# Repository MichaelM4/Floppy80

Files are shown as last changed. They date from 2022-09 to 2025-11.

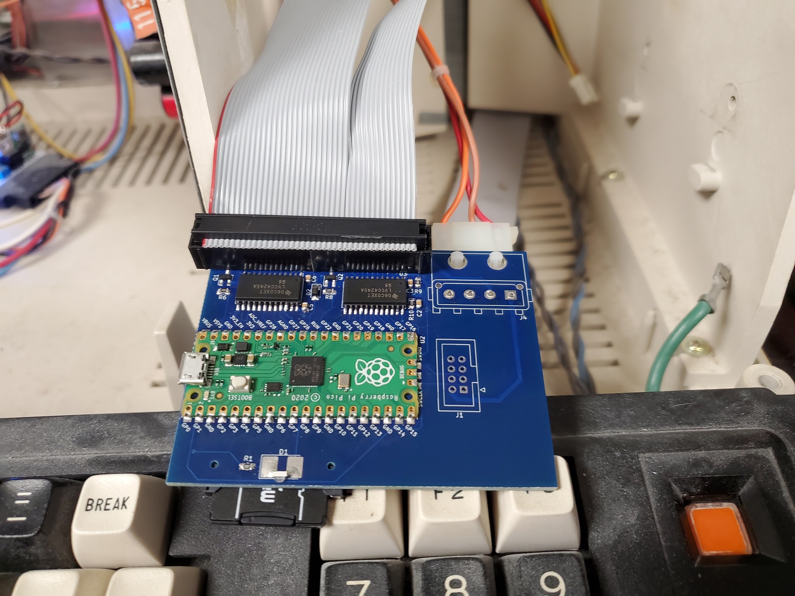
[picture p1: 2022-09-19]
20220129_120431.jpg

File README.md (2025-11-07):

########################################################################

Floppy 80 for the TRS-80 Model 3/4 NGA

The Floppy80 emulates up to four floppy drives.

Configuration of the Floppy80 is performed with the placement of
files on the SD-Card inserted in its card reader.
The files are as follows:

boot.cfg
- specified the defaul ini file to load at reset of the Floppy80
  when the floppy 80 boots or is reset it reads the contents of
  the boot.cfg to determine the default configuration ini file.

ini files
- specifies the disk images to load after reset.

  ini options
  - Drive0 - specified the image to load for drive :0
  - Drive1 - specified the image to load for drive :1
  - Drive2 - specified the image to load for drive :2
  - Drive3 - specified the image to load for drive :3

dmk files
- these are virtual disk images with a specific file format
  that allows them to be generated and used with a number
  of existing programs and simulators.

hfe files
- these are virtual disk images with a specific file format
  that allows them to be generated and used with a number
  of existing programs and simulators.

########################################################################

FDC utility
- Is a utility to interact with the Floppy80 from within the
  TRS-80 Model 3/4 operating environment.  Versions of FDC exist
  for the following operating systems

  - CPM
  - LDOS
  - TRSDOS

  FDC.COM is used with the CP/M OS and
  FDC/CMD is used with the rest.

  Usage

  FDC OPT PARM1:drive

  Where:
  - OPT is one of the following
    - STA - returns the status of the Floppy80.
    - INI - switches between tyhe differnt ini file on the SD-Card.
    - DMK - allows the mounting of DMK disk images in the root folder
            of the SD-Card for a specified drive (0, 1, 2 or 3).
    - IMP - imports a file from the root folder of the SD-Card
            into one of the mounted disk images (0, 1, 2 or 3).

  FDC STA
  - Displays the contects to the ini file specified by boot.cfg

  FDC INI filename.exe
  - filename.exe is optional.  If not specified and list of ini files
    on the SD-Card will be displayed allow you to select the one to
    write to boot.cfg.  When specified FDC will bypass the file
    selection process.

  FDC DMK filename.exe n
  - filename.exe:n is optional.  When specified it will mount
    the dmk file names by filename.exe into the drive specified
    by n.  For example

    FDC DMK LDOS-DATA.DMK 2

    will mount the dmk file LDOS-DATA.DMK into drive :2

    If filename.exe:n is not specfied a list of dmk files
    will be listed allowing you to select on and the drive
    to mount it into.

  FDC IMP filename.exe:n
  - imports the specified file from the root folder of the
    FAT32 formated SD-Card to the disk image indicated by n.

########################################################################

Building Source
- Floppy80 firmware
  - Uses VSCode and the Pi Pico extension.

- FDC TRS (utility for the TRSDOS related utility)
  
  - zmac fdc.asm

- FDC CP/M (utility for the CP/M related utility)
  1. Import the source file onto a working CP/M diskette.
  
       D:\TRS-80\TRSUtils\trswrite cpm-work2.dmk -o fdc.c
     
  2. Run TRS80GP loading the CP/M disk images.
     
       start trs80gp -m4 -vs -frehd -frehd_dir source -turbo -mem 128 -d0 M4-CPM-MONTEZUMA-v22.dmk -d1 cpm-hc-disk.dmk -d2 cpm-work1.dmk -d3 cpm-work2.dmk
     
  3. Compile the C source using the Hi-Tech C compilier.

     b:
     c d:fdc.c

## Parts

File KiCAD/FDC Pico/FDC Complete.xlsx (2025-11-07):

Qty | Description | Cost | Part Number | Supplier
 | PCB Components | $14.05
 | PCB FDC | $2.00
 | PCB Card Edge | $1.00
1 | 2 x 20 male header | $0.50 | ED10529-ND | Digikey
1 | 2x20 female to female ribbon cable (30 cm) | $2.50 ea |  | Amazon
 |  | $17.55

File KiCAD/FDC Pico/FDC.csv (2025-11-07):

Source: | D:\TRS-80\Projects\fdc\KiCAD\FDC Pico\FDC.kicad_sch
Date: | 3/24/2022 11:33
Tool: | Eeschema (6.0.1)
Generator: | C:\Program Files\KiCad\6.0\bin\scripting\plugins/bom_csv_grouped_by_value.py
Component Count: | 20
Individual Components:
Item | Qty | Reference(s) | Value | Cost | Digikey | Manufacturer | Mouser | Vendor
 |  | C2 | 100nF | 0.1 | 732-8080-1-ND
 |  | C3 | 100nF | 0.1 | 732-8080-1-ND
 |  | C5 | 100nF | 0.1 | 732-8080-1-ND
 |  | C6 | 100nF | 0.1 | 732-8080-1-ND
 |  | D1 | LED | 0.72 | 754-1519-1-ND
 |  | D2 | 1N4148WTR | 0.14 | 1655-1360-1-ND
 |  | J1 | Conn_02x04_Odd_Even |  |  |  |  | 900-0702460801-ND
 |  | J3 | SD_Card | 4.3 | 478-4058-1-ND | 145638109511859+ | 581-145638109511859+
 |  | J4 | Conn_01x04_Female | 2.22 | A25430-ND | 641737-1
 |  | J5 | Conn_02x20_Odd_Even | 0.5 | ED10529-ND
 |  | Q1 | SBC817-40LT1G | 0.28 | SBC817-40LT1GOSCT-ND
 |  | Q2 | SBC817-40LT1G | 0.28 | SBC817-40LT1GOSCT-ND
 |  | R1 | 100 | 0.1 | RMCF0805FT100RCT-ND
 |  | R6 | 1k | 0.1 | A106056CT-ND
 |  | R8 | 1k | 0.1 | A106056CT-ND
 |  | R9 | 4.7k | 0.1 | A129757CT-ND
 |  | R10 | 4.7k | 0.1 | A129757CT-ND
 |  | U2 | Pico | 4 | 2648-SC0915CT-ND
 |  | U3 | SN74LVCC4245ADWR | 1.82 | 296-26634-1-ND
 |  | U5 | SN74LVCC4245ADWR | 1.82 | 296-26634-1-ND
Collated Components:
Item | Qty | Reference(s) | Value | Cost | Digikey | Manufacturer | Mouser | Vendor
1 | 4 | C2, C3, C5, C6 | 100nF | 0.1 | 732-8080-1-ND
2 | 1 | D1 | LED | 0.72 | 754-1519-1-ND
3 | 1 | D2 | 1N4148WTR | 0.14 | 1655-1360-1-ND
4 | 1 | J1 | Conn_02x04_Odd_Even |  |  |  |  | 900-0702460801-ND
5 | 1 | J3 | SD_Card | 4.3 | 478-4058-1-ND | 145638109511859+ | 581-145638109511859+
6 | 1 | J4 | Conn_01x04_Female | 2.22 | A25430-ND | 641737-1
7 | 1 | J5 | Conn_02x20_Odd_Even | 0.5 | ED10529-ND
8 | 2 | Q1, Q2 | SBC817-40LT1G | 0.28 | SBC817-40LT1GOSCT-ND
9 | 1 | R1 | 100 | 0.1 | RMCF0805FT100RCT-ND
10 | 2 | R6, R8 | 1k | 0.1 | A106056CT-ND
11 | 2 | R9, R10 | 4.7k | 0.1 | A129757CT-ND
12 | 1 | U2 | Pico | 4 | 2648-SC0915CT-ND
13 | 2 | U3, U5 | SN74LVCC4245ADWR | 1.82 | 296-26634-1-ND

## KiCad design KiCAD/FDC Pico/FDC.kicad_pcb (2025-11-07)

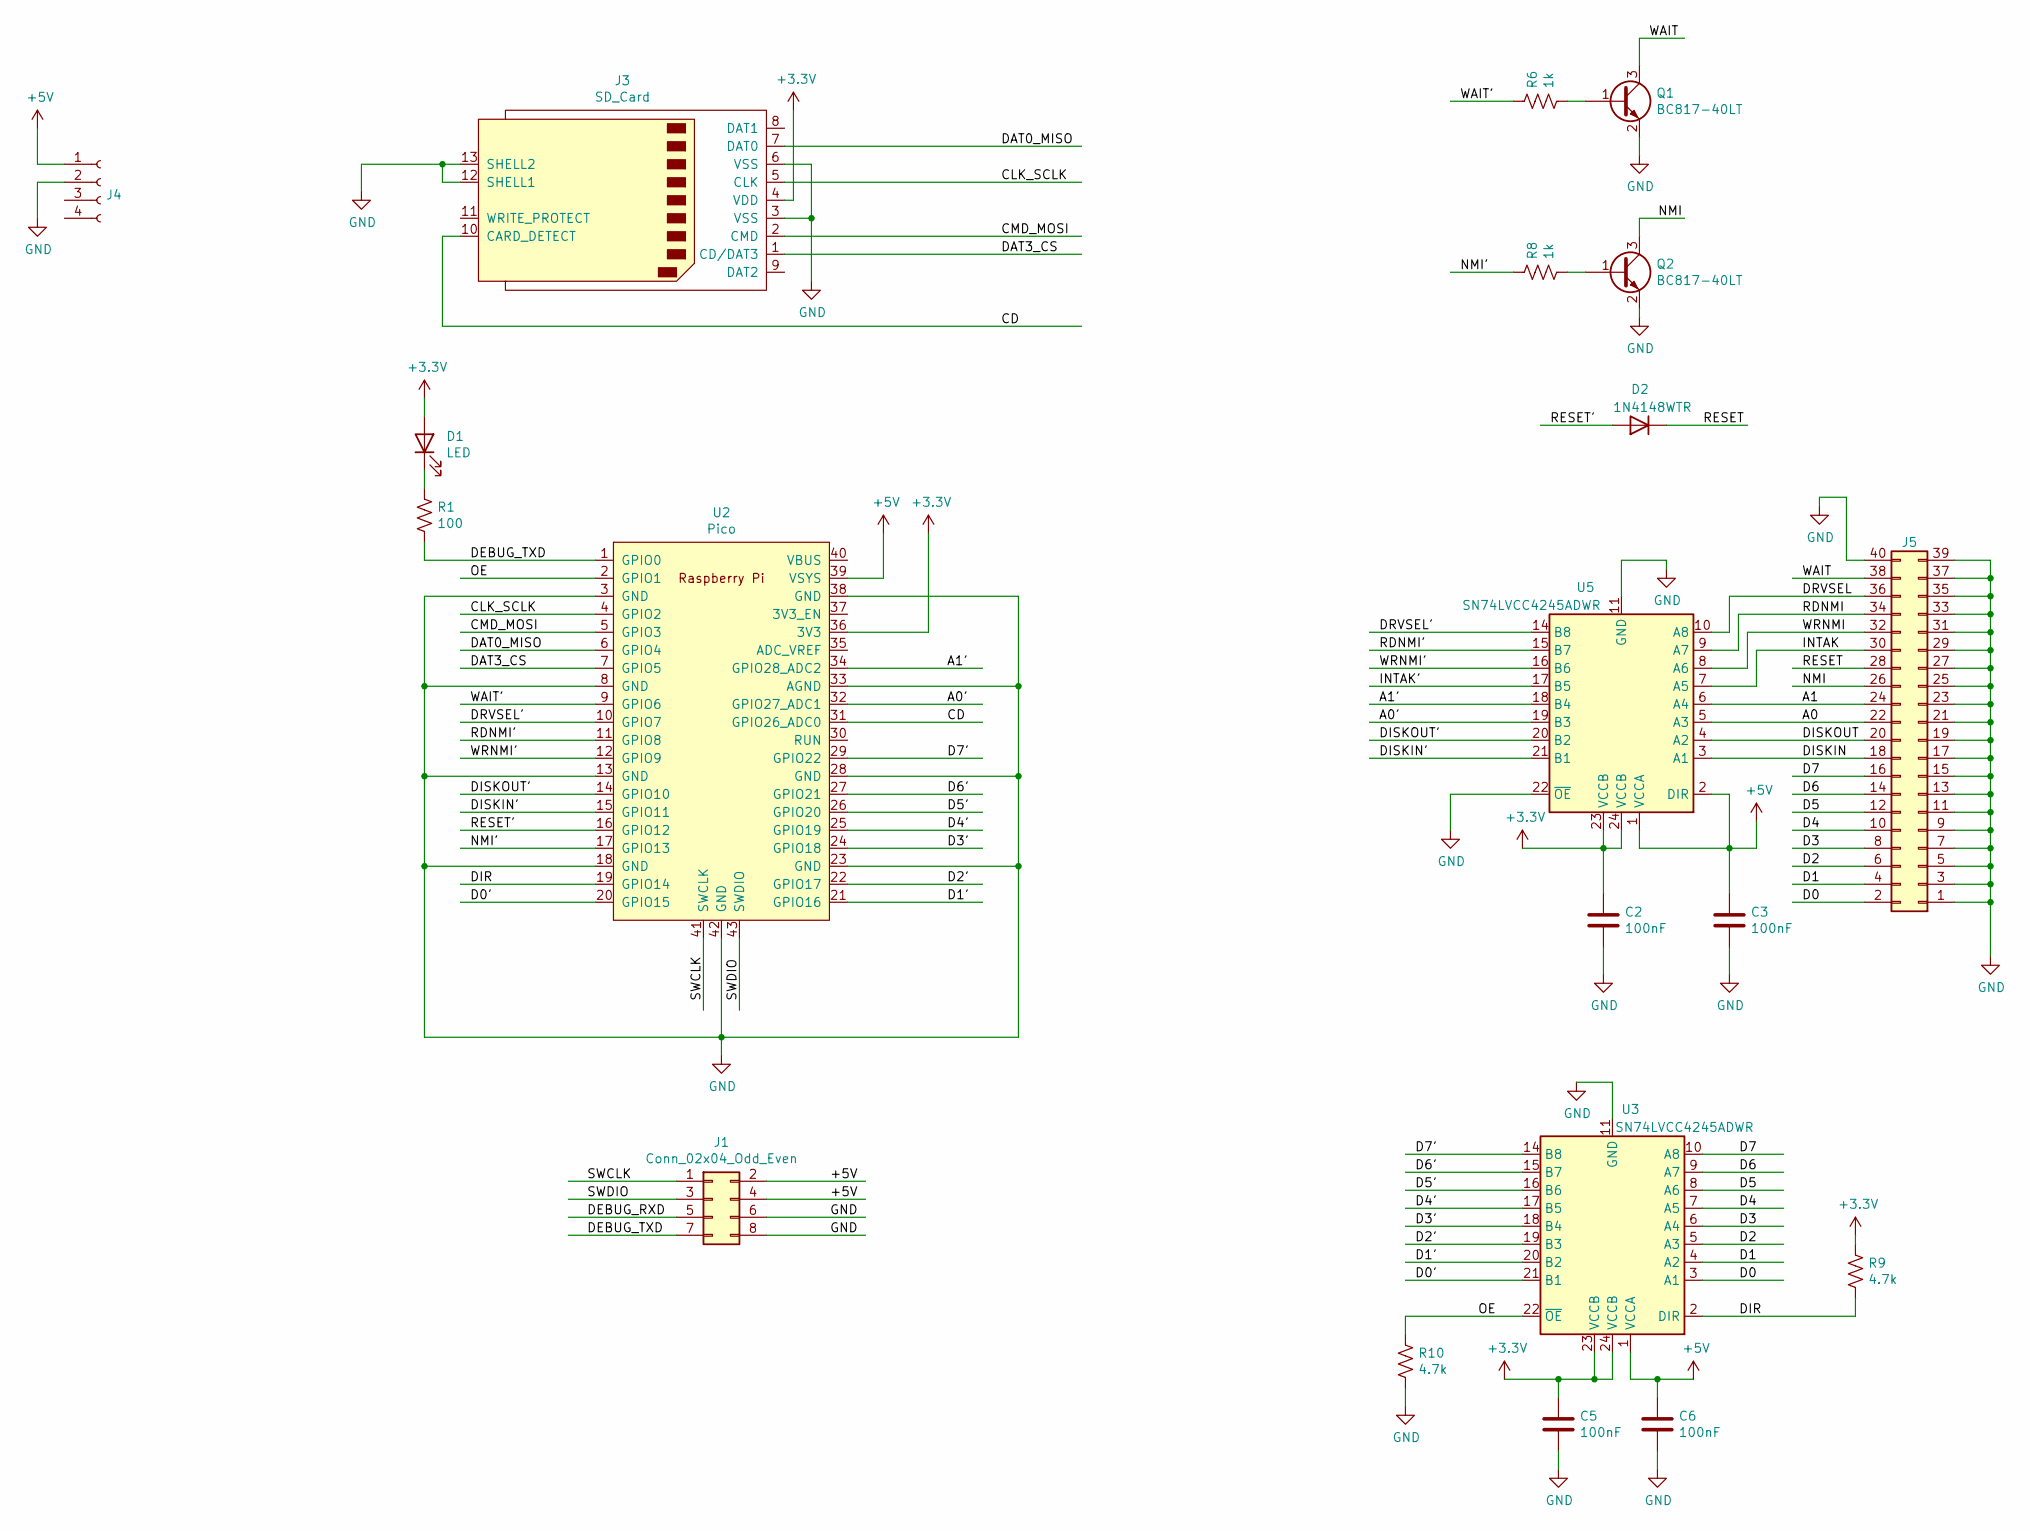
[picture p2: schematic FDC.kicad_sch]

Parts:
C2, C3, C5, C6: 100nF; C_0603_1608Metric_Pad1.08x0.95mm_HandSolder; Digikey 732-8080-1-ND
D1: LED; LED_2816_7142Metric_Pad3.20x4.45mm_HandSolder; Digikey 754-1519-1-ND
D2: 1N4148WTR; D_1206_3216Metric_Pad1.42x1.75mm_HandSolder; Digikey 1655-1360-1-ND
J1: Conn_02x04_Odd_Even; IDC-Header_2x04_P2.54mm_Vertical
J3: SD_Card; SD_Kyocera_145638109511859+; Digikey 478-4058-1-ND
J4: Conn_01x04_Female; TE_MATE-N-LOK_350211-1_1x04_P5.08mm_Horizontal; Digikey A25430-ND
J5: Conn_02x20_Odd_Even; PinHeader_2x20_P2.54mm_Vertical; Digikey ED10529-ND
Q1: BC817-40LT; SOT-23_Handsoldering; Digikey BC817-40LT3GOSCT-ND
Q2: BC817-40LT; SOT-23_Handsoldering; Digikey BC817-40FDICT-ND
R1: 100; R_0805_2012Metric_Pad1.20x1.40mm_HandSolder; Digikey RMCF0805FT100RCT-ND
R6, R8: 1k; R_0805_2012Metric_Pad1.20x1.40mm_HandSolder; Digikey A106056CT-ND
R9, R10: 4.7k; R_0805_2012Metric_Pad1.20x1.40mm_HandSolder; Digikey A129757CT-ND
U2: Pico; RPi_Pico_SMD_TH; Digikey 2648-SC0915CT-ND
U3, U5: SN74LVCC4245ADWR; SOIC-24W_7.5x15.4mm_P1.27mm; Digikey 296-26634-1-ND

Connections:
+3V3: C2.1, C5.1, D1.2 (A), J3.4 (VDD), R9.1, U2.36 (3V3), U3.23 (VCCB), U3.24 (VCCB), U5.23 (VCCB), U5.24 (VCCB)
+5V: C3.1, C6.1, J1.2, J1.4, J4.1, U2.39 (VSYS), U3.1 (VCCA), U5.1 (VCCA), U5.2 (DIR)
/A0: J5.22, U5.5 (A3)
/A0': U2.32 (GPIO27_ADC1), U5.19 (B3)
/A1: J5.24, U5.6 (A4)
/A1': U2.34 (GPIO28_ADC2), U5.18 (B4)
/CD: J3.10 (CARD_DETECT), U2.31 (GPIO26_ADC0)
/CLK_SCLK: J3.5 (CLK), U2.4 (GPIO2)
/CMD_MOSI: J3.2 (CMD), U2.5 (GPIO3)
/D0: J5.2, U3.3 (A1)
/D0': U2.20 (GPIO15), U3.21 (B1)
/D1: J5.4, U3.4 (A2)
/D1': U2.21 (GPIO16), U3.20 (B2)
/D2: J5.6, U3.5 (A3)
/D2': U2.22 (GPIO17), U3.19 (B3)
/D3: J5.8, U3.6 (A4)
/D3': U2.24 (GPIO18), U3.18 (B4)
/D4: J5.10, U3.7 (A5)
/D4': U2.25 (GPIO19), U3.17 (B5)
/D5: J5.12, U3.8 (A6)
/D5': U2.26 (GPIO20), U3.16 (B6)
/D6: J5.14, U3.9 (A7)
/D6': U2.27 (GPIO21), U3.15 (B7)
/D7: J5.16, U3.10 (A8)
/D7': U2.29 (GPIO22), U3.14 (B8)
/DAT0_MISO: J3.7 (DAT0), U2.6 (GPIO4)
/DAT3_CS: J3.1 (CD/DAT3), U2.7 (GPIO5)
/DEBUG_TXD: J1.7, R1.2, U2.1 (GPIO0)
/DIR: R9.2, U2.19 (GPIO14), U3.2 (DIR)
/DISKIN: J5.18, U5.3 (A1)
/DISKIN': U2.15 (GPIO11), U5.21 (B1)
/DISKOUT: J5.20, U5.4 (A2)
/DISKOUT': U2.14 (GPIO10), U5.20 (B2)
/DRVSEL: J5.36, U5.10 (A8)
/DRVSEL': U2.10 (GPIO7), U5.14 (B8)
/INTAK: J5.30, U5.7 (A5)
/NMI: J5.26, Q2.3 (C)
/NMI': R8.1, U2.17 (GPIO13)
/OE: R10.1, U2.2 (GPIO1), U3.22 (~OE)
/RDNMI: J5.34, U5.9 (A7)
/RDNMI': U2.11 (GPIO8), U5.15 (B7)
/RESET: D2.1 (K), J5.28
/RESET': D2.2 (A), U2.16 (GPIO12)
/SWCLK: J1.1, U2.41 (SWCLK)
/SWDIO: J1.3, U2.43 (SWDIO)
/WAIT: J5.38, Q1.3 (C)
/WAIT': R6.1, U2.9 (GPIO6)
/WRNMI: J5.32, U5.8 (A6)
/WRNMI': U2.12 (GPIO9), U5.16 (B6)
GND: C2.2, C3.2, C5.2, C6.2, J1.6, J1.8, J3.3 (VSS), J3.6 (VSS), J3.12 (SHELL1), J3.13 (SHELL2), J4.2, J5.1, J5.3, J5.5, J5.7, J5.9, J5.11, J5.13, J5.15, J5.17, J5.19, J5.21, J5.23, J5.25, J5.27, J5.29, J5.31, J5.33, J5.35, J5.37, J5.39, J5.40, Q1.2 (E), Q2.2 (E), R10.2, U2.3 (GND), U2.8 (GND), U2.13 (GND), U2.18 (GND), U2.23 (GND), U2.28 (GND), U2.33 (AGND), U2.38 (GND), U2.42 (GND), U3.11 (GND), U3.12 (GND), U3.13 (GND), U5.11 (GND), U5.12 (GND), U5.13 (GND), U5.22 (~OE)
unnamed: D1.1 (K), R1.1
unnamed: Q1.1 (B), R6.2
unnamed: Q2.1 (B), R8.2

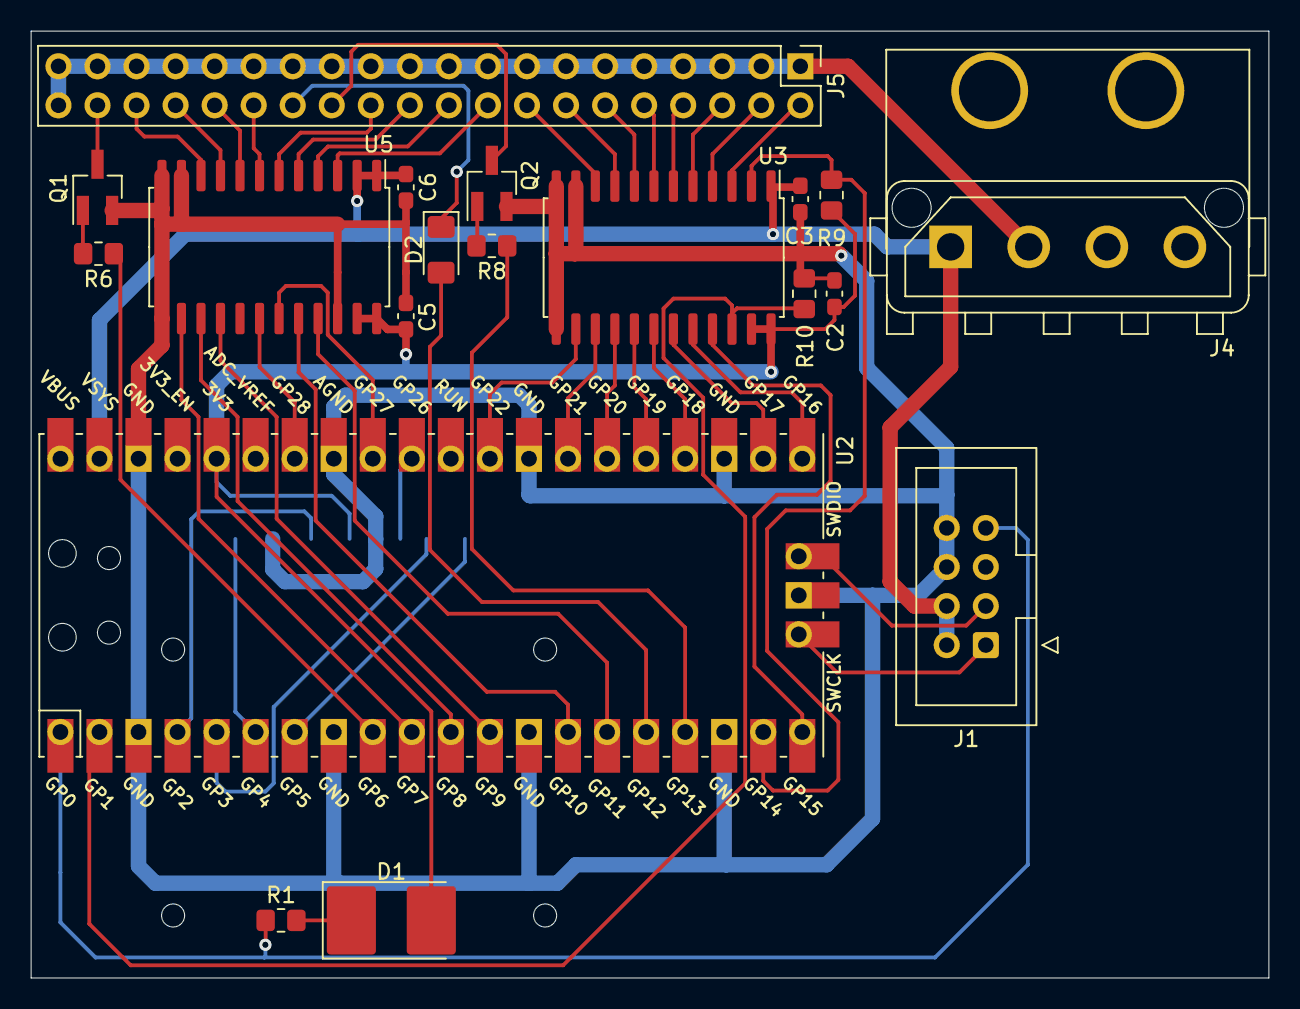
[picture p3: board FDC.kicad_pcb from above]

Board: 2 copper layers, 80.5 x 61.6 mm, 20 parts (1 on the bottom side), 53 nets.

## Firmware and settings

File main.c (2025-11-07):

#include <stdio.h>
#include <string.h>
#include "pico/stdlib.h"

#include "hardware/pio.h"
#include "hardware/irq.h"
#include "hardware/regs/intctrl.h"
#include "hardware/clocks.h"
#include "hardware/structs/systick.h"

#include "fdc.pio.h"
#include "Defines.h"
#include "sd_core.h"
#include "fdc.h"
#include "system.h"

#if (ENABLE_TRACE_LOG == 1)
	void RecordBusHistory(DWORD dwBus, BYTE byData);
#endif

///////////////////////////////////////////////////////////////////////////////
// API documentions is located at
// https://raspberrypi.github.io/pico-sdk-doxygen/
///////////////////////////////////////////////////////////////////////////////

///////////////////////////////////////////////////////////////////////////////
// to get memory usage of the compilied program enter
//
//     size build/fdc.elf
//
// in a bash terminal window
//
// Output is
// - text indicates code size (Read Only)
// - data is initialized data (R/W)
// - bss is uninitialize data (R/W)
///////////////////////////////////////////////////////////////////////////////

#define ENABLE_LED 1
#define HOST_SEQUENCE_COUNT 9

BYTE g_byHostSequence[HOST_SEQUENCE_COUNT] = {0x80, 0x7F, 0x81, 0xFE, 0x82, 0xFD, 0x83, 0xFC, 0x84};

//-----------------------------------------------------------------------------

pio_sm_config g_pio_config;
PIO           g_pio;
uint          g_sm, g_offset;

DWORD         g_dwPreviousTimeCount;
DWORD         g_dwRotationTime;
DWORD         g_dwIndexTime;
DWORD         g_dwResetTime;
BYTE          g_byMonitorReset;

BYTE          g_byMotorWasOn;
BYTE          g_byFlushTraceBuffer;

uint32_t      g_nTimeNow;
uint32_t      g_nPrevTime;

//-----------------------------------------------------------------------------
void DetectHostSequnce(BYTE byData)
{
	if ((g_FDC.nWrHostSequence < HOST_SEQUENCE_COUNT) && (g_byHostSequence[g_FDC.nWrHostSequence] == byData))
	{
		++g_FDC.nWrHostSequence;
	}
	else
	{
		g_FDC.nWrHostSequence = 0;
		g_FDC.nRdHostSequence = 0;
	}
}

///////////////////////////////////////////////////////////////////////////////
// restart pio code to release WAIT state
void ReleaseWait(void)
{
	// push pin direction mask into tx fifo (this way the pio state machine does not need to generate it)
	pio_sm_put(g_pio, g_sm, ~GPIO_IN_MASK >> WAIT_PIN);

	// restart the pio state machine at its first instruction (the address for which is g_offset)
	// set x, g_offset
	//   [3 bit opcode]      = 111
	//   [5 bits = delay]    = 00000
	//   [3 bits detination] = 001 = x
	//   [5 bits data]       = g_offset
	//   -------------------------------
	//   1110  0000 0010 0000 + [offset]
	pio_sm_exec(g_pio, g_sm, 0xE020 + g_offset);

	// mov pc, x
	//   [3 bit opcode]      = 101
	//   [5 bits = delay]    = 00000
	//   [3 bits detination] = 101 = pc
	//   [2 bits Op]         = 00  = None
	//   [3 bits Source]     = 001 = x
	//   -------------------------------
	//   1010  0000 1010 0001
	pio_sm_exec(g_pio, g_sm, 0xA0A1);
}

//----------------------------------------------------------------------------
void GetCommandText(char* psz, BYTE byCmd)
{
	char szBuf[128];
	
	*psz = 0;

	if ((byCmd & 0xF0) == 0) // 0000xxxx
	{
		strcpy(psz, "CMD: Restore");
	}
	else if ((byCmd & 0xF0) == 0x10) // 0001xxxx
	{
		sprintf(psz, "CMD: SEEK 0x%02X, From 0x%02X", g_FDC.byData, g_FDC.byTrack);
	}
	else if ((byCmd & 0xF0) == 0x20) // 0010xxxx
	{
		strcpy(psz, "CMD: Step, Do Not Update Track Register");
	}
	else if ((byCmd & 0xF0) == 0x30) // 0011xxxx
	{
		strcpy(psz, "CMD: Step, Update Track Register");
	}
	else if ((byCmd & 0xF0) == 0x40) // 0100xxxx
	{
		strcpy(psz, "CMD: Step In, Do Not Update Track Register");
	}
	else if ((byCmd & 0xF0) == 0x50) // 0101xxxx
	{
		strcpy(psz, "CMD: Step In, Update Track Register");
	}
	else if ((byCmd & 0xF0) == 0x60) // 0110xxxx
	{
		strcpy(psz, "CMD: Step Out, Do Not Update Track Register");
	}
	else if ((byCmd & 0xF0) == 0x70) // 0111xxxx
	{
		strcpy(psz, "CMD: Step Out, Update Track Register");
	}
	else if ((byCmd & 0xF0) == 0x80) // 1000xxxx
	{
		sprintf(psz, "CMD: RSEC: 0x%02X TRK: 0x%02X", g_FDC.bySector, g_FDC.byTrack);
	}
	else if ((byCmd & 0xF0) == 0x90) // 1001xxxx
	{
		strcpy(psz, "CMD: RSEC: Multiple Record");
	}
	else if ((byCmd & 0xF0) == 0xA0) // 1010xxxx
	{
		sprintf(psz, "CMD: WSEC: 0x%02X TRK: 0x%02X", g_FDC.bySector, g_FDC.byTrack);
	}
	else if ((byCmd & 0xF0) == 0xB0) // 1011xxxx
	{
		strcpy(psz, "CMD: WSEC: Multiple Record");
	}
	else if ((byCmd & 0xF0) == 0xC0) // 1100xxxx
	{
		strcpy(psz, "CMD: Read Address");
	}
	else if ((byCmd & 0xF0) == 0xD0) // 1101xxxx
	{
		sprintf(psz, "CMD: Force Interrupt (0x%02X)", byCmd);
	}
	else if ((byCmd & 0xF0) == 0xE0) // 1110xxxx
	{
		sprintf(psz, "CMD: RTRK: 0x%02X", g_FDC.byTrack);
	}
	else if ((byCmd & 0xF0) == 0xF0) // 1110xxxx
	{
		sprintf(psz, "CMD: WTRK: 0x%02X", g_FDC.byTrack);
	}
	else
	{
		strcpy(psz, "CMD: Unknown");
	}
}

//-----------------------------------------------------------------------------
void __not_in_flash_func(fdc_isr)(void)
{
	DWORD dwBus;
	WORD  wReg, wCom;
	BYTE  byData;
	BYTE  byReleaseWait;
	BYTE  byReqCount;
	char  szBuf[128];

	dwBus  = gpio_get_all();
	byData = (dwBus >> D0_PIN) & 0xFF;

	byReleaseWait = 1;
	byReqCount    = 0;

	// INTR_MASK (DISKIN, DISKOUT, WRNMI, RDNMI and DRVSEL bits 1)
	// if ((dwBus & INTR_MASK) == INTR_MASK) then DRVSEL, RDNMI, WRNMI, DISKOUT and DISKIN are all high

	if ((dwBus & DISKIN_MASK) == 0) // the DISKIN is low (READ from FDC), put data on bus
	{
		++byReqCount;

		// make all pins outputs
		gpio_set_dir_out_masked(DATA_BUS_MASK);

		wReg = (dwBus >> A0_PIN) & 0x03;

		switch (wReg)
		{
			case 0:
				byData = FdcGetStatus();
			
				++g_FDC.nReadStatusCount;

				if (g_FDC.stStatus.byIntrRequest)
				{
					g_FDC.byNmiStatusReg = 0xFF; // inverted state of all bits low except INTRQ
					g_FDC.stStatus.byIntrRequest = 0;
				}

				g_FDC.nWrHostSequence = 0;
				break;

			case 1:
				byData = g_FDC.byTrack;
				g_FDC.nWrHostSequence = 0;
				break;

			case 2:
				byData = g_FDC.bySector;
				g_FDC.nWrHostSequence = 0;
				break;

			case 3:
				if ((g_FDC.byDriveSel == 0x0F) && (g_FDC.nProcessFunction == psSendData))
				{
					byData = g_FDC.byTransferBuffer[g_FDC.nTrasferIndex];
					++g_FDC.nTrasferIndex;
					g_FDC.dwStateCounter = 10000;

					if (g_FDC.nTrasferIndex >= g_FDC.nTransferSize)
					{
						g_FDC.nProcessFunction = psIdle;
						g_FDC.stStatus.byDataRequest = 0;

						if (g_FDC.byBackupDriveSel != 0)
						{
							g_FDC.byDriveSel = g_FDC.byBackupDriveSel;
							g_FDC.byBackupDriveSel = 0;
						}
					}
				}
				else
				{
					byData = g_FDC.byData;
					g_FDC.stStatus.byDataRequest = 0;
					++g_FDC.nDataRegReadCount;

					if (g_FDC.nWrHostSequence == HOST_SEQUENCE_COUNT)
					{
						byData = g_byHostSequence[g_FDC.nRdHostSequence];
						++g_FDC.nRdHostSequence;
					}
				}

				break;
		}

		gpio_put_masked(DATA_BUS_MASK, byData << D0_PIN);

		#if (ENABLE_TRACE_LOG == 1)
			RecordBusHistory(dwBus, byData);
		#endif
	}

	if ((dwBus & RDNMI_MASK) == 0) // the RDNMI is low (read NMI latch from FDC), put data on bus
	{
		++byReqCount;

		// make all pins outputs
		gpio_set_dir_out_masked(DATA_BUS_MASK);

		byData = g_FDC.byNmiStatusReg;

		gpio_put_masked(DATA_BUS_MASK, byData << D0_PIN);

		#if (ENABLE_TRACE_LOG == 1)
			RecordBusHistory(dwBus, byData);
		#endif
	}
	
	if ((dwBus & DISKOUT_MASK) == 0) // DISKOUT (WRITE to FDC)
	{
		++byReqCount;

		wReg = (dwBus >> A0_PIN) & 0x03;

		switch (wReg)
		{
			case 0: // address 0xF0/240, command register
				g_FDC.byCommandReg    = byData;
				g_FDC.byCommandType   = FdcGetCommandType(byData);
				g_FDC.byNmiStatusReg  = 0xFF;
				g_FDC.nWrHostSequence = 0;

				if (g_FDC.stStatus.byIntrRequest)
				{
					g_FDC.byNmiStatusReg = 0xFF; // inverted state of all bits low except INTRQ
					g_FDC.stStatus.byIntrRequest = 0;
				}

				memset(&g_FDC.stStatus, 0, sizeof(g_FDC.stStatus));

				if (g_FDC.byDriveSel == 0x0F)
				{
					g_FDC.byCommandReceived      = 1;
					g_FDC.stStatus.byBusy        = 1;
					g_FDC.stStatus.byDataRequest = 0;
				}
				else
				{
					wCom = g_FDC.byCommandReg & 0xF0;

					if (wCom == 0xD0) // 0xD0 is Force Interrupt command
					{
						g_nWaitTime             = time_us_64();
						g_FDC.byCommandType     = 4;
						g_tdTrack.nReadSize     = 0;
						g_tdTrack.nReadCount    = 0;
						g_tdTrack.nWriteSize    = 0;
						g_FDC.byCurCommand      = g_FDC.byCommandReg;
						g_FDC.byIntrEnable      = g_FDC.byCurCommand & 0x0F;
						g_FDC.nProcessFunction  = psIdle;
						g_FDC.byCommandReceived = 0;
						memset(&g_FDC.stStatus, 0, sizeof(g_FDC.stStatus));
					}
					else
					{
						g_FDC.byCommandReceived = 1;
						g_FDC.stStatus.byBusy   = 1;
					}
				}

				break;

			case 1: // address 0xF1/241, track register
				g_FDC.byTrack = byData;
				g_FDC.nWrHostSequence = 0;
				break;

			case 2: // address 0xF2/242, sector register
				g_FDC.bySector        = byData;
				g_FDC.nWrHostSequence = 0;
				break;

			case 3: // address 0xF3/243, data register
				g_FDC.byData = byData;
				g_FDC.stStatus.byDataRequest = 0;
				DetectHostSequnce(byData);
				break;
		}

		#if (ENABLE_TRACE_LOG == 1)
			RecordBusHistory(dwBus, byData);
		#endif
	}

	if ((dwBus & WRNMI_MASK) == 0) // WRNMI (WRITE to FDC)
	{
		++byReqCount;

		g_FDC.byNmiMaskReg = byData;

		if (byData & 0x80)
		{
			g_FDC.byNmiMaskReg = byData;
		}
		else
		{
			g_FDC.stStatus.byIntrRequest = 0;
		}

		#if (ENABLE_TRACE_LOG == 1)
			RecordBusHistory(dwBus, byData);
		#endif
	}

	if ((dwBus & DRVSEL_MASK) == 0) // DRVSEL (WRITE to FDC)
	{
		++byReqCount;

		if (((byData & 0x0F) == 0x0F) && // host drive select?
			(g_FDC.byBackupDriveSel == 0))
		{
			g_FDC.byBackupDriveSel = g_FDC.byDriveSel;
		}

		g_FDC.byDriveSel = byData;

		++g_FDC.nDrvSelWriteCount;

		// do not allow a wait output if WAITTIMEOUT, INTRQ or DRQ are active
		if (g_FDC.stStatus.byIntrRequest == 0)
		{
			// in "real" hardware the wait is activated on rising edge of the DRV_SEL input
			// here it is already activated by the PIO code on every FDC read/write operation
			if ((byData & 0x40) != 0) // activate WAIT
			{
				g_FDC.dwWaitTimeoutCount = 2000;
				g_FDC.byWaitOutput = 1;
				byReleaseWait = 0;
			}
		}

		g_FDC.dwMotorOnTimer = 2000000;

		if (ENABLE_LED)
		{
			gpio_put(RED_LED_PIN, 0);
		}

		#if (ENABLE_TRACE_LOG == 1)
			RecordBusHistory(dwBus, byData);
		#endif
	}

	if (byReqCount > 1)
	{
		++byReqCount;
	}

	if (byReleaseWait)
	{
		// re-enable automatic WAIT generation
		ReleaseWait(); // allow pio state machine to resume
	}

    irq_clear(PIO0_IRQ_0);
    pio_interrupt_clear(g_pio, 0);
}

///////////////////////////////////////////////////////////////////////////////
// GPIO	NET 	IN	OUT
//-----------------------------------------------------------------------------
// 0	LED			*	(Motor ON LED)
// 1	OE			*	(BUS level translator Output Enable)
// 2	CLK			*	(SD-Card)
// 3	CMD			*	(SD-Card)
//
// 4	DAT0	*		(SD-Card)
// 5	DAT3		*	(SD-Card)
// 6	WAIT		*	(Wait control, high pulls wait low)
// 7	DRVSEL	*		(write to the Drive Select Register)
//
// 8	RDNMI	*		(read the NMI register)
// 9	WRNMI	*		(write to the NMI register)
// 10	DISKOUT	*		(write to FDC, register identified by A0, A1)
// 11	DISKIN	*		(read from FDC, register identified by A0, A1)
//
// 12	RESET	*		(pulled low by reset)
// 13	NMI 		*	(NMI control, high pulls NMI low)
// 14	DIR			*	(set the direction of the bus level translator)
// 15	D0		*	*	(bit 0 of the data bus)
//
// 16	D1		*	*	(bit 1 of the data bus)
// 17	D2		*	*	(bit 2 of the data bus)
// 18	D3		*	*	(bit 3 of the data bus)
// 19	D4		*	*	(bit 4 of the data bus)
//
// 20	D5		*	*	(bit 5 of the data bus)
// 21	D6		*	*	(bit 6 of the data bus)
// 22	D7		*	*	(bit 7 of the data bus)
// 23	-
//
// 24	-
// 25	-
// 26	-
// 27	A0		*		(bit 0 of address/regsister select)
//
// 28	A1		*		(bit 1 of address/regsister select)
// 29	-
// 30	-
// 31	-
//-----------------------------------------------------------------------------
void InitGPIO(void)
{
    // configure pins for input
    gpio_init_mask(GPIO_IN_MASK);

    gpio_init(RESET_PIN);
    gpio_set_dir(RESET_PIN, GPIO_IN);
    gpio_set_pulls(RESET_PIN, true, false);

    gpio_init(A0_PIN);
    gpio_set_dir(A0_PIN, GPIO_IN);

    gpio_init(A1_PIN);
    gpio_set_dir(A1_PIN, GPIO_IN);

    gpio_init(D0_PIN);
    gpio_set_dir(D0_PIN, GPIO_IN);

    gpio_init(D1_PIN);
    gpio_set_dir(D1_PIN, GPIO_IN);

    gpio_init(D2_PIN);
    gpio_set_dir(D2_PIN, GPIO_IN);

    gpio_init(D3_PIN);
    gpio_set_dir(D3_PIN, GPIO_IN);

    gpio_init(D4_PIN);
    gpio_set_dir(D4_PIN, GPIO_IN);

    gpio_init(D5_PIN);
    gpio_set_dir(D5_PIN, GPIO_IN);

    gpio_init(D6_PIN);
    gpio_set_dir(D6_PIN, GPIO_IN);

    gpio_init(D7_PIN);
    gpio_set_dir(D7_PIN, GPIO_IN);

    // configure pins for output
    gpio_init(NMI_PIN);
    gpio_set_dir(NMI_PIN, GPIO_OUT);
    gpio_put(NMI_PIN, 0);

	if (ENABLE_LED)
	{
		gpio_init(RED_LED_PIN);
		gpio_set_dir(RED_LED_PIN, GPIO_OUT);
		gpio_put(RED_LED_PIN, 0);
	}

    gpio_init(OE_PIN);
    gpio_set_dir(OE_PIN, GPIO_OUT);
    gpio_put(OE_PIN, 0);

    gpio_init(WAIT_PIN);
    gpio_set_dir(WAIT_PIN, GPIO_OUT);
    gpio_put(WAIT_PIN, 1); // activate wait until FDC initialization is complete

    gpio_init(DIR_PIN);
    gpio_set_dir(DIR_PIN, GPIO_OUT);
    gpio_put(DIR_PIN, 1); // Z80 to FDC
}

///////////////////////////////////////////////////////////////////////////////
void UpdateCounters(void)
{
	uint32_t nDiff;

	g_nTimeNow  = time_us_32();

	if (g_nTimeNow >= g_nPrevTime)
	{
		nDiff = g_nTimeNow - g_nPrevTime;
	}
	else
	{
		nDiff = 0x100000000 - g_nPrevTime + g_nTimeNow;
	}

	g_nPrevTime = g_nTimeNow;

	if (g_FDC.dwWaitTimeoutCount > 0)
	{
		g_FDC.dwWaitTimeoutCount = CountDown(g_FDC.dwWaitTimeoutCount, nDiff);
		
		if (g_FDC.dwWaitTimeoutCount == 0) // release wait line
		{
			FdcReleaseWait();
		}
	}

	if (g_FDC.dwMotorOnTimer != 0)
	{
		if (ENABLE_LED)
		{
			gpio_put(RED_LED_PIN, 0);
		}
		
		g_byMotorWasOn = 1;

		g_FDC.dwMotorOnTimer  = CountDown(g_FDC.dwMotorOnTimer, nDiff);
		g_FDC.dwRotationCount = CountUp(g_FDC.dwRotationCount, nDiff);

		// (g_dwTimerFrequency / 5) = count to make one full rotation of the diskette (200 ms at 300 RPM)
		if (g_FDC.dwRotationCount >= g_dwRotationTime)
		{
			g_FDC.dwRotationCount -= g_dwRotationTime;
		}

		if (g_FDC.dwRotationCount < g_dwIndexTime)
		{
			g_FDC.stStatus.byIndex = 1;
		}
		else
		{
			g_FDC.stStatus.byIndex = 0;
		}
	}
	else
	{
		if (ENABLE_LED)
		{
			gpio_put(RED_LED_PIN, 1);
		}

		if (g_byMotorWasOn)
		{
			g_byMotorWasOn = 0;
		}
	}

	if (gpio_get(RESET_PIN) == 0)
	{
		if (g_byMonitorReset)
		{
			g_FDC.dwResetCount = CountUp(g_FDC.dwResetCount, nDiff);

			if (g_FDC.dwResetCount >= g_dwResetTime) // ~ 1ms duration
			{
				g_FDC.byResetFDC = 1;
			}
		}
	}
	else
	{
		g_FDC.dwResetCount = 0;
		g_byMonitorReset   = TRUE;
	}

	if (g_FDC.dwStateCounter > 0)
	{
		g_FDC.dwStateCounter = CountDown(g_FDC.dwStateCounter, nDiff);
	}

	if (get_cd())		// 0 => card removed; 1 => card inserted;
	{
		if (g_dwSdCardPresenceCount < g_dwSdCardMaxPresenceCount)
		{
			g_dwSdCardPresenceCount = CountUp(g_dwSdCardPresenceCount, nDiff);
		}
	}
	else
	{
		g_dwSdCardPresenceCount = 0;
	}
}

///////////////////////////////////////////////////////////////////////////////
int main()
{
	int i;

    stdio_init_all();

    systick_hw->csr = 0x5;
    systick_hw->rvr = 0x00FFFFFF;

	g_byMotorWasOn = 0;
	g_byFlushTraceBuffer = 0;
	g_nTimeNow  = time_us_32();
	g_nPrevTime = g_nTimeNow;

    InitGPIO();

	if (ENABLE_LED)
	{
		gpio_put(RED_LED_PIN, 1);
		gpio_put(RED_LED_PIN, 0);
	}

    InitVars();

    g_pio    = pio0;
    g_sm     = pio_claim_unused_sm(g_pio, true);
    g_offset = pio_add_program(g_pio, &fdc_program);

    fdc_program_init(g_pio, g_sm, g_offset, WAIT_PIN, DRVSEL_PIN, DIR_PIN, &g_pio_config);

    // Start running the PIO program in the state machine
    pio_sm_set_enabled(g_pio, g_sm, true);

    irq_set_exclusive_handler(PIO0_IRQ_0, fdc_isr);
    irq_set_enabled(PIO0_IRQ_0, true);
    pio_set_irq0_source_enabled(g_pio, pis_interrupt0, true);

	// push pin direction mask into tx fifo
	pio_sm_put(g_pio, g_sm, ~GPIO_IN_MASK >> WAIT_PIN);

   	SDHC_Init();
    FileSystemInit();
 	FdcInit();

	#if (ENABLE_TRACE_LOG == 1)
		InitBusTrace();
	#endif

    gpio_put(WAIT_PIN, 0); // release wait
	
    while (true)
    {
		UpdateCounters();
        FdcServiceStateMachine();

		#if (ENABLE_TRACE_LOG == 1)
			if (g_byFlushTraceBuffer)
			{
				FlushTraceBuffer();
				g_byFlushTraceBuffer = 0;
			}
		#endif
    }   
}

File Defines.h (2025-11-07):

#ifndef _H_DEFINES_
#define _H_DEFINES_

#include <stdio.h>

// set to 1 to enable capture of bus activity logging to sd-card
#define ENABLE_TRACE_LOG 0

///////////////////////////////////////////////////////////////////////////////////////////////////
// Bit - 31 30 29 28 27 26 25 24 23 22 21 20 19 18 17 16 15 14  13  12  11     10      9     8     7      6    5    4    3   2   1  0
// Net -          A1 A0 CD          D7 D6 D5 D4 D3 D2 D1 D0 DIR NMI RST DISKIN DISKOUT WRNMI RDNMI DRVSEL WAIT DAT3 DAT0 CMD CLK OE TXD
//       0  0  0  1  1  1  0  0  0  1  1  1  1  1  1  1  1  0   0   1   1      1       1     1     1      0    0    0    0   0   0  0
//       ----------  ----------  ----------  ----------  ------------   ----------------------     ------------------    ------------
// Hex            1           C           7           F             9                        F                      8               0
#define GPIO_IN_MASK 0x1C7F9F80

#define DRVSEL_MASK   0x00000080
#define RDNMI_MASK    0x00000100
#define WRNMI_MASK    0x00000200
#define DISKOUT_MASK  0x00000400
#define DISKIN_MASK   0x00000800

#define INTR_MASK     (DRVSEL_MASK | RDNMI_MASK | WRNMI_MASK | DISKOUT_MASK | DISKIN_MASK)

#define ADDRESS_MASK  0x18000000
#define DATA_BUS_MASK 0x007F8000

#define NMI_MASK      0x00002000
#define WAIT_MASK     0x00000040

#define RED_LED_PIN 0
#define OE_PIN      1
#define CLK_SCLK    2
#define CMD_MOSI    3
#define DAT0_MISO   4
#define DAT3_CS     5

#define WAIT_PIN    6
#define DRVSEL_PIN  7
#define RDNMI_PIN   8
#define WRNMI_PIN   9
#define DISKOUT_PIN 10
#define DISKIN_PIN  11

#define RESET_PIN   12
#define NMI_PIN     13
#define DIR_PIN     14

#define D0_PIN      15
#define D1_PIN      16
#define D2_PIN      17
#define D3_PIN      18
#define D4_PIN      19
#define D5_PIN      20
#define D6_PIN      21
#define D7_PIN      22

#define CD_PIN      26

#define A0_PIN      27
#define A1_PIN      28

#define DIR_PIN_MASK  0x4000

///////////////////////////////////////////////////////////////////////////////////////////////////

#define BOARD_REVISION 2

extern int g_nRevBoard;

///////////////////////////////////////////////////////////////////////////////////////////////////

// Low Power Timer Overflow Rates in Hz
#define TIMER_OVERFLOW_RATE				2000

///////////////////////////////////////////////////////////////////////////////////////////////////
// generic defines/equates

#ifndef TRUE
	#define FALSE	0
	#define TRUE	1
#endif

///////////////////////////////////////////////////////////////////////////////////////////////////
// typedefs

typedef long long          	INT64;
typedef unsigned long long 	UINT64;
typedef unsigned long      	UINT32;
typedef long               	INT32;
typedef unsigned short     	UINT16;
typedef short              	INT16;
typedef unsigned char		    UINT8;
typedef signed char        	INT8;
typedef signed char        	SCHAR;
typedef unsigned long      	DWORD;
typedef unsigned short     	WORD;
typedef unsigned char      	BYTE;
typedef char		       	    CHAR;

typedef struct {
   unsigned long long nSectorsTotal;
   unsigned long long nSectorsFree;
   unsigned long long nSectorSize;

   unsigned long nClustersTotal;
   unsigned long nClustersFree;
   unsigned long nClustersUsed;
   unsigned long nClustersBad;
   unsigned long nClusterSize;
} F_SPACE;
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
